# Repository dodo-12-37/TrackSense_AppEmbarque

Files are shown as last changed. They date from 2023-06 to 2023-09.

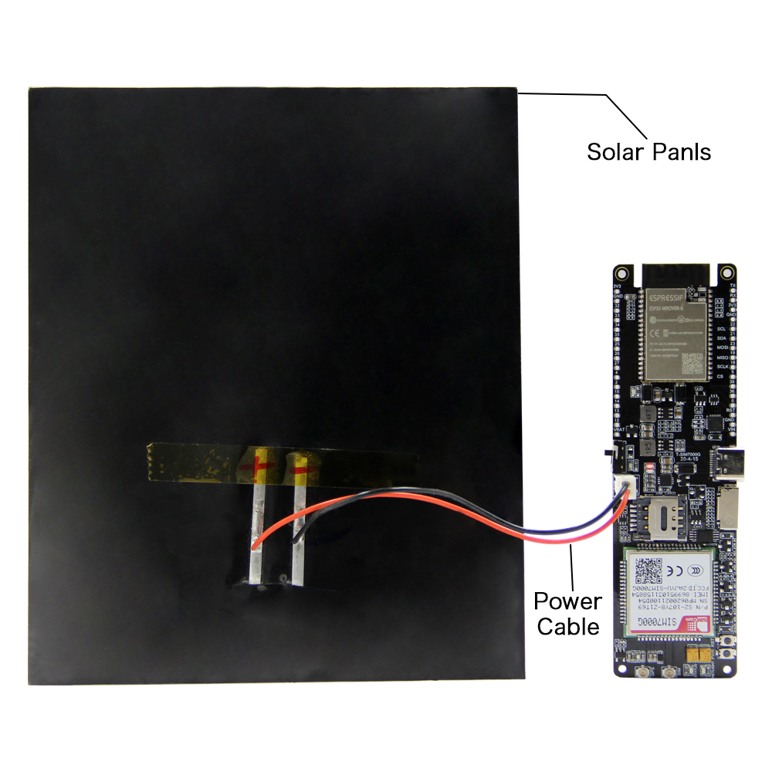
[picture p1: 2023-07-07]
Références Composants/LILYGO T-SIM7000G - ESP32/Installation Panneau Solaire.jpg

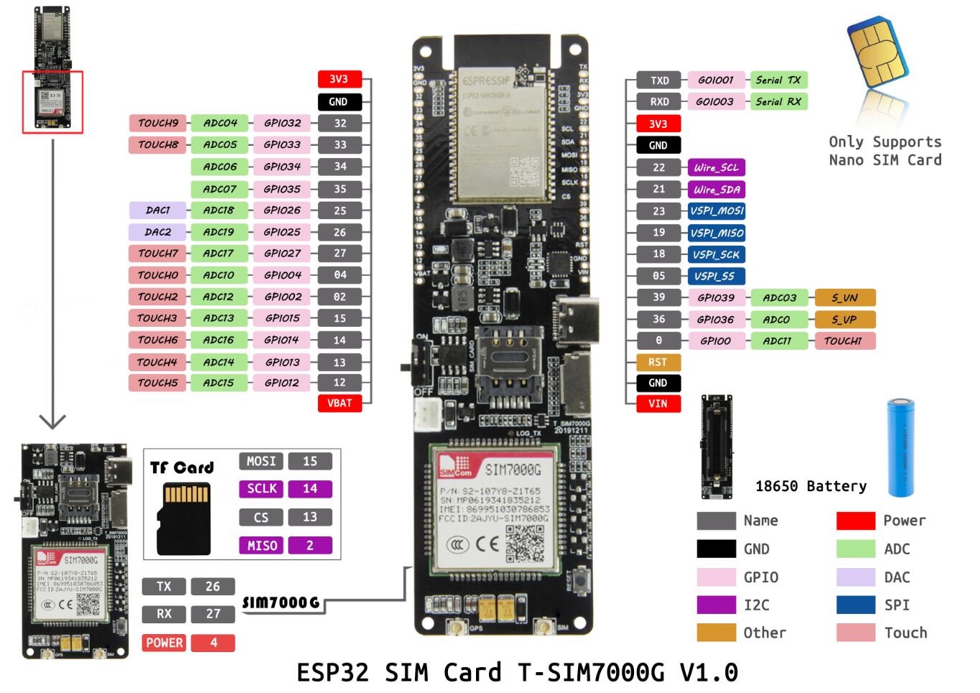
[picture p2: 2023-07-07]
Références Composants/LILYGO T-SIM7000G - ESP32/LILYGO-SIM7000G-ESP32-V1_0_pinout.jpg

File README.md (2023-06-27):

# 420-W57-SF_E23_4394_TrackSense_AppEmbarque
Dépôt de l'Application Embarqué du Projet Synthèse pour le cours de Programmation, bases de données et serveurs – AEC (LEA.D4). 

Nous ferons la création d'un objet connecté nommé le TrackSense. Cette objet sera principalement utilisé sur un vélo ou un piéton.

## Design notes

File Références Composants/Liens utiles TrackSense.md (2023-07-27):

# Liste de liens utiles pour TrackSense

## Pièces achetées
- [TFT Display 1.28 Inch TFT LCD Display Module Round RGB 240*240 GC9A01 Driver 4 Wire SPI Interface 240x240 PCB For Arduino](https://www.aliexpress.com/item/1005004069703494.html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)
  - MEILLEUR LIEN : [**Using GC9A01 Round LCD Modules**](https://dronebotworkshop.com/gc9a01/)
  - [**Library Bodmer/TFT_eSPI**](https://github.com/Bodmer/TFT_eSPI/blob/master/User_Setups/Setup200_GC9A01.h)
  - [Library carlfriess/GC9A01_demo]()
  - [Exemple de code pour l'écran](https://www.makerfabs.com/gc9a01-1.28-inch-round-lcd-module.html)
  - [Adafruit_GC9A01A Library](https://github.com/adafruit/Adafruit_GC9A01A)  
  - [Adafruit GFX Library](https://github.com/adafruit/Adafruit-GFX-Library/blob/master/README.md)
  - [**ESP32 SPI Communication: Set Pins, Multiple SPI Bus Interfaces, and Peripherals (Arduino IDE)**](https://randomnerdtutorials.com/esp32-spi-communication-arduino/)
  - Exemple de code : [Photographic album using ESP32 and GC9A01 round screen](https://giltesa.com/en/2021/01/05/photographic-album-using-esp32-and-gc9a01-round-screen)
  - [Video : GC9A01 Round LCD with ESP32 & Arduino](https://www.youtube.com/watch?v=k2c2zCmC_X0)
  - Très bonne référence complète, mais pas modèle exacte [**Waveshare 1.28inch LCD Module**](https://www.waveshare.com/wiki/1.28inch_LCD_Module)
  - [**Waveshare : 240×240, General 1.28inch Round LCD Display Module, 65K RGB**](https://www.waveshare.com/1.28inch-LCD-Module.htm)
  - [**IPS LCD 1.28″ 240×240 RGB Round Display GC9A01**](https://protosupplies.com/product/ips-lcd-128-round-square-display-gc9a01-copy/)
  - [1.28inch LCD Display Module, IPS Screen, 65K RGB, 240 × 240 Resolution, SPI Interface. ](https://www.waveshare.com/wiki/1.28inch_LCD_Module#Introduction)
  - []()
  - []()
  - []()

- [LILYGO® TTGO T-SIM7000G 4MB / 16MB Module ESP32-WROVER-B Chip SIM Card WiFi Bluetooth 18650 Battery Holder Solar Charge Board](https://www.aliexpress.com/item/1005003094951052.html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)
  - [**Dépot GitHub Officiel LILYGO**](https://github.com/Xinyuan-LilyGO/LilyGO-T-SIM7000G)
  - [T-SIM7000G SIM Development Board ESP32 Wireless Module](https://www.lilygo.cc/products/t-sim7000g?variant=42275516776629)
  - [LILYGO® TTGO Accessories Shield LoRa 868/915 Mhz](https://www.tindie.com/products/lilygo/lilygo-ttgo-accessories-shield-lora-868915-mhz/)
  - [**ACOPTEX Guide to LILYGO T-SIM7000G ESP32 development board- AT communication**](https://acoptex.com/wp/guide-to-lilygo-t-sim7000g-esp32-development-board/)
  - [**LILYGO T-SIM7000G ESP32: Get GPS Data (Latitude, Longitude, Altitude, and more)**](https://randomnerdtutorials.com/lilygo-t-sim7000g-esp32-gps-data/)
  - [**Getting Started with LILYGO T-SIM7000G ESP32 (LTE, GPRS, and GPS)**](https://randomnerdtutorials.com/lilygo-t-sim7000g-esp32-lte-gprs-gps/)
  - [?? GNSS – How to use GNSS feature on Simcom Modules? ??](https://m2msupport.net/m2msupport/gnss-how-to-use-gnss-feature-on-simcom-modules/)
  - []()
  - []()
  - []()
  - [GSM/GPRS/GPS Shield (B), Arduino Shield Based on SIM808 ](https://www.waveshare.com/wiki/GSM/GPRS/GPS_Shield_(B))

- [GY-87 ou HW-290](https://fr.aliexpress.com/item/4000234539826.html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)
  - [Interfacing GY-87 IMU MPU6050 HMC5883L BMP085 Module with Arduino](https://electropeak.com/learn/interfacing-gy-87-10dof-imu-mpu6050-hmc5883l-bmp085-module-with-arduino/)
  - [HMC5883L_Simple Library](https://github.com/sleemanj/HMC5883L_Simple)
  - [GY-87 10DOF MPU6050 HMC5883L BMP180 Sensor Module](https://store.roboticsbd.com/sensors/382-gy-87-10dof-mpu6050-hmc5883l-bmp180-sensor-module-robotics-bangladesh.html)
  - [**Use and Calibrate HMC5883L Digital Compass**](https://www.best-microcontroller-projects.com/hmc5883l.html)
  - []()
  - []()
  - []()

- [MPU-6050]()
  - [**I2C Device Library** The I2C Device Library (i2cdevlib) is a collection of mostly uniform and well-documented classes to provide simple and intuitive interfaces to I2C devices.](https://github.com/jrowberg/i2cdevlib/tree/master/Arduino/MPU6050)
  - [MPU6050 by Electronic Cats - Library for Arduino](https://github.com/ElectronicCats/mpu6050/tree/master)
  - [What is MPU6050?](https://github.com/ElectronicCats/mpu6050/wiki/1.-What-is-MPU6050%3F#features)
  - [VIDEO : ESP32 Web Server with MPU-6050 Accelerometer and Gyroscope (3D object representation)](https://www.youtube.com/watch?v=dXcF-Uqa-gw)
  - []()
  - []()
  - []()

- [Buzzer SFM-27 ou SFM-20B](https://fr.aliexpress.com/item/1005001792688572.html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)
  - [Images dimension buzzer](https://fr.aliexpress.com/item/1005005426676025.html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,scm-url:1007.40050.281175.0,pvid:f82a8dd0-6433-49ed-a130-f7840a425f60,tpp_buckets:668%232846%238107%231934&pdp_npi=3%40dis%21CAD%210.58%210.52%21%21%21%21%21%402103250716890035395333740e7c3e%2112000033021292153%21rec%21CA%21)
  - []()
  - []()
  - []()

- [10 Pack TTP223B Digital Touch Capacitive Sensor Switch Module DIY for Arduino Raspberry Pi](https://www.aliexpress.com/item/1005004822891026.html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)
  - [Vidéo du fonctionnement des boutons](https://www.youtube.com/watch?v=V6ORKSxHLN0)
  - [Tutorial for TTP223 Touch Sensor Module ( Capacitive)](https://www.instructables.com/Tutorial-for-TTP223-Touch-Sensor-Module-Capacitive/)
  - Exemple avec capteur différent : [How to use a TTP223 based touch switch](https://diyusthad.com/2019/06/how-to-use-ttp223-based-touch-switch.html)
  - []()
  - []()
  - [CapacitiveSensor Library : CapacitiveSensor lets you create sensors that can detect touch or proximity.](https://github.com/PaulStoffregen/CapacitiveSensor)
  - [Capacitive Sensing Library](https://playground.arduino.cc/Main/CapacitiveSensor/)
  - [Vidéo explication : Capacitive Sensing Library](https://www.youtube.com/watch?v=jhtY_Hn5jBM)
  - []()
  - []()

- [Connecteur female headers PCB, long, 2.54mm, 11/12mm, 2mm, 3mm, 4mm, 6mm, 8mm, 10mm, 15mm, 20/40 broches](https://fr.aliexpress.com/item/1005003961219838.html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,scm-url:1007.40050.281175.0,pvid:3dd93779-9ecc-4d7b-9a69-51549ba19462,tpp_buckets:668%232846%238116%232002&pdp_npi=3%40dis%21CAD%211.65%211.65%21%21%21%21%21%402101ec1f16884816869006605eff6d%2112000027575194850%21rec%21CA%21)
  - [Dessin connecteurs female headers](https://fr.aliexpress.com/item/4000979967513.html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,scm-url:1007.40050.281175.0,pvid:e7105b2a-5874-40fd-b602-fba5c134012f,tpp_buckets:668%232846%238116%232002&pdp_npi=3%40dis%21CAD%211.0%210.95%21%21%21%21%21%402101ead816884800553916301ef787%2110000013144422244%21rec%21CA%21)
  - []()
  - []()
  - []()
  - []()
  - []()

## Tilt Compass
### Exemple avec bon capteurs (GY-87, MPU-6050, QMC5883L)
- [3 Axis Magnetometer Tilt Compensation](https://www.best-microcontroller-projects.com/magnetometer-tilt-compensation.html)
- [Vidéo Tilt Compensated Digital Compass based on AVR](https://www.youtube.com/watch?v=spmMMIMboPY)
- [Exemple GitHub visakhanc/eCompass](https://github.com/visakhanc/eCompass/blob/master/README.md)
- [Tutorial: How to use the GY-521 module (MPU-6050 breakout board) with the Arduino Uno](https://mschoeffler.com/2017/10/05/tutorial-how-to-use-the-gy-521-module-mpu-6050-breakout-board-with-the-arduino-uno/)
- []()
- []()
- []()
- []()
- []()

### Exemple avec mauvais capteurs
- [How to Use GY511 Module With Arduino [Make a Digital Compass]](https://www.instructables.com/How-to-Use-GY511-Module-With-Arduino-Make-a-Digita/)
- [Tilt Compensated Compass IvenSense MPU-9250 & MPU-6050 accelerometer / gyro & an AK8963 magnetometer](https://www.instructables.com/Tilt-Compensated-Compass/)
- []()
- []()
- []()
- []()
- []()
- []()
- []()
- []()

## Create PCB with EasyEDA Designer
- [Document Tutorial](https://docs.easyeda.com/en/Introduction/Schematic-Capture/index.html)
- [How to Make Custom ESP32 Board in 3 Hours | Full Tutorial](https://www.youtube.com/watch?app=desktop&v=S_p0YV-JlfU&feature=youtu.be)
- [Get quote for PCB - JLCPCB](https://cart.jlcpcb.com/quote)
- [Explication des connecteurs JST](https://www.mattmillman.com/info/crimpconnectors/common-jst-connector-types/#shsr)
- [Autre explication des connecteurs JST](https://www.ourpcb.com/jst-connector-types.html)
- []()
- []()
- []()
- []()
- []()
- []()

# Résumé 04 juillet

- [x] Ajouter 2ème rangée de pins pour connecter les CHEVELUS. 
- [x] Mesuré le speaker piézo et y trouver une place.
- [x] Ajouter un connecteur pour le speaker piézo.
- [x] Deux connectiques pour l'écran TFT. Un sur la TFCard et un sur le VSPI.
- [x] Ajouter deux connecteurs pour les boutons. (Vérifier pour une résistance???)
- [x] Ajouter des résistances pour les connecteurs I2C.
- [x] Enlever les connecteurs I2C en surplus.
- [x] Mettre le GY-87 directement sur le PCB.
- [x] Mettre des pins VCC et GND pour les boutons. (Et pins infos aussi ???)
- [ ] 

Fusion 360 fabriquer boitier

cd "C:\Program Files\Oracle\VirtualBox\"
VBoxManage.exe modifyvm "VM_MacOS_AppMobile_2" --cpuidset 00000001 000106e5 00100800 0098e3fd bfebfbff
VBoxManage setextradata "VM_MacOS_AppMobile_2" "VBoxInternal/Devices/efi/0/Config/DmiSystemProduct" "iMac19,3"
VBoxManage setextradata "VM_MacOS_AppMobile_2" "VBoxInternal/Devices/efi/0/Config/DmiSystemVersion" "1.0"
VBoxManage setextradata "VM_MacOS_AppMobile_2" "VBoxInternal/Devices/efi/0/Config/DmiBoardProduct" "Iloveapple"
VBoxManage setextradata "VM_MacOS_AppMobile_2" "VBoxInternal/Devices/smc/0/Config/DeviceKey" "ourhardworkbythesewordsguardedpleasedontsteal(c)AppleComputerInc"
VBoxManage setextradata "VM_MacOS_AppMobile_2" "VBoxInternal/Devices/smc/0/Config/GetKeyFromRealSMC" 0
VBoxManage setextradata "VM_MacOS_AppMobile_2" "VBoxInternal/TM/TSCMode" "RealTSCOffset"

Gravité	Code	Description	Projet	Fichier	Ligne	État de la suppression
Erreur	APT2098	xml_microsoft_maui_essentials_fileprovider_file_paths.xml.flat: error: failed to open file. "xml_microsoft_maui_essentials_fileprovider_file_paths.xml.flat: error: failed to open file.".	BluetoothLEConnection	C:\Program Files\dotnet\packs\Microsoft.Android.Sdk.Windows\32.0.485\tools\Xamarin.Android.Aapt2.targets	123

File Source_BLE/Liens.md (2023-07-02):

# Liens diverses

- [Architecture Bluetooth de l'ESP (en)](file:///D:/T%C3%A9l%C3%A9chargements/esp32_bluetooth_architecture_en-1.pdf)
- [Exemple de Mise en oeuvre du Bluetooth BLE sur ESP32 (fr)](http://tvaira.free.fr/bts-sn/activites/activite-ble/activite-ble-esp32.html)
- [Exemple ESP32 BLE Server and Client (en)](https://randomnerdtutorials.com/esp32-ble-server-client/)
- [Exemple ESP32 BLE Server and Client (en)](https://randomnerdtutorials.com/esp32-bluetooth-low-energy-ble-arduino-ide/)
- [Exemple ESP32 BLE Server and Client (en)](https://randomnerdtutorials.com/esp32-ble-server-client/#ESP32-BLE-Server)
- [Référence GitHub](https://github.com/nkolban/ESP32_BLE_Arduino)
- [Référence GitHub](https://github.com/nkolban/esp32-snippets)
- [Liste des UUID normés](https://www.bluetooth.com/specifications/assigned-numbers/)

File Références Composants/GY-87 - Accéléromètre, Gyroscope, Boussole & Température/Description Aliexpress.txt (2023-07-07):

 Description

10DOF modules (three-axis gyroscope + triaxial accelerometer + three-axis magnetic field + Pressure)

Immersion Gold PCB process

Using the chip: MPU6050 + HMC5883L + BMP180

Power supply :3-5v

Means of communication: IIC communication protocol (fully compatible with 3-5v system containing LLC circuit)

Size: 2.2cm * 1.7cm

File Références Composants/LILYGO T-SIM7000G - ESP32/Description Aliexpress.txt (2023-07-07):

Description :

Hardware Specifications

Main chip

ESP32-WROVER-B,SIM7000G

Flash Memory

4M Flash / 8M PSRAM

Interface

USB,SD Card,Solar Input interface

Car Clock

40MHz

Button

Reset,Power switch

SIM Card Size

Nano SIM Card

Antenna

SIM Antenna，GPS Antenna

Operating Temperature Range

-40-85 degrees

Power Specifications

Working Voltage

5v input

Charging Current

780mA

Working Curent

About 200mA

Solar input voltage range

4.4-6v

USB

TYPE-C 3.0

JST connector

2pin 2.0MM

Battery holder

18650 battery holder

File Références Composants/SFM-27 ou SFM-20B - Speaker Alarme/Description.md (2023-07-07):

**Description:**  
[Lien info (pas celui acheter...)](https://www.aliexpress.com/item/1005005560547607.html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)

- Color: Black
- Alarm Diameter: 22mm/0.86"
- Alarm Height: 10mm/0.39”
- 2 Mounting Holes distance: 30mm/1.18"
- 2 Wires length: 90mm/3.54"
- Buzzer Type: Piezoelectric
- Sound Pressure Level: 95 dB
- Rate Voltage: 12V DC
- Operating Voltage: 3 - 24V
- Max Current Rating: 10mA
- Frequency: 3900±500Hz
- Drive Method: Drive Circuit Built in Mounting Holes
- Sound: "Di" Continuous

**Package includes:**
1 x 95DB Piezoelectric Buzzer Alarm

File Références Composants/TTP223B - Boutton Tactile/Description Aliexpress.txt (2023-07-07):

Description
Report Item

The Digital Sensor TTP223B Module Capacitive Touch Switch is based on a touch-sensing IC (TTP223B) capacitive touch switch module. Allows you to remove the worry of conventional push-type keys.

Digital Capacitive Touch Switch Module is based on TTP223B. Normally, it outputs low and keeps at low power state. When a touch is sensed on the circular marked region, it outputs high and switches to the quick response state. When not being touched for 12 seconds, it switches to low power state again.

If the module is mounted in the surfaces of non-metallic materials such as plastic, glass, acrylic, you can make the keys hidden in the walls and desks.

In addition to the thin paper ( non-metallic ) covering the surface of the module, as long as the correct location of the touch, you can make hidden in the walls, desktops and other parts of buttons.

Touch Sensor Interface:
Control Interface: A total of three pins (GND, VCC, SIG), GND to the ground, VCC is the power supply, SIG digital signal output pin
Power Indicator: Green LED, power on the right that is shiny
Touch area: Similar to a fingerprint icon inside the area, you can touch the trigger finger.
Positioning holes: 4 M2 screws positioning hole diameter is 2.2mm, the positioning of the module is easy to install, to achieve inter-module combination.

Features :
Low power consumption
Power supply for 2 ~ 5.5V DC
Can replace the traditional touch of a button
Four M2 screws positioning holes for easy installation
Output Pin Sink Current (@ VCC = 3V, VOL = 0.6V) : 8 mA
Output pin pull-up current (@ VCC = 3V, VOH = 2.4V) : 4 mA

Package Includes :
10 x Digital Sensor TTP223B Module Capacitive Touch Switch

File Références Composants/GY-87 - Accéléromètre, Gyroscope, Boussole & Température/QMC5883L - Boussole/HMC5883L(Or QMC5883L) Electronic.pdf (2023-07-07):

# HMC5883L(Or QMC5883L) Electronic Compass

In ourProfessional Kit, there exist two kinds of Compass module. One kind uses HMC5883L module, the other uses QMC5883L module. You will get one of them when you get the Professional Kit. They don't have too much difference. HMC5883Lis made by Honeywell. but because the production is about to be stopped, so we use a similar compass module-QMC5883Linstead. QMC5883Lis made by a Chinese company, they get the production authorization of HMC5883L from Honeywell, and rename it QMC5883L. So QMC5883Land HMC5883Lbasically are the same, they shares the same hardware design. Just their register is a bit different. We only need to change the software a bit.

When you got the Professional Kit, please check which compass module you get based on the following picture. The HMC5883Lhas a label "L883"on it, while QMC5883Lcomes with "5883"

HMC5883LElectronic Compass | QMC5883LElectronic Compass
HMC5883LElectronic Compass | QMC5883LElectronic Compass

# HMC5883L Electronic Compass

## Introduction

3-Axis Compass module, I2C based Honeywell HMC5883 digital compass. This ASIC is equipped with high resolution HMC118X magneto-resistive sensors and a 12-bitADC. It provides compass heading accuracy up to 1° to 2°. Signal conditioning like amplification, automatic degaussing strap drivers and offset cancellation are inbuilt. This module also includes a MIC5205-2.5 voltage regulator for power supply requirement. Hence user can connect any 3.3V to 6V DC power supply.

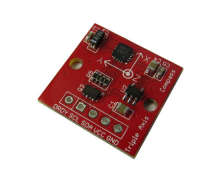
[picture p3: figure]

## Features

- I2C interface
- Compatible with 3.3V-5.0V voltage level
- Max 116Hz output rate
- High heading accuracy

## Usage

Below is a registermap that might help you understand what you can get from this module. There are totally 13 registers provided by HMC5883L. Out of three registers - Configuration registerA, Configuration RegisterB and Mode Register decide the working mode of the device. The remaining registers are read only data output registers, status register and identification registers.

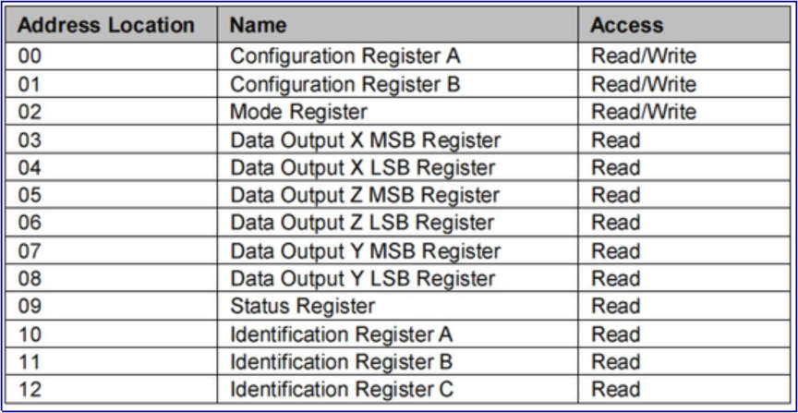
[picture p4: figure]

This demo is going to show you how to read raw data, how to calibrate the data with your local magnetic declination angle and how to get heading angle.
First off, before any action you are going to take, you need to prepare a parameter you are going to use in your demo. That's your local magnetic declination.
You can find it out in degree via the magnetic declination webpage. For example, mine is -2°37’, which is -2.617 degree.
Then transfer it from degree to radians, and there you get the "declinationAngle". For example, in my case, declinationAngle = -2.617 / （2*π）= -0.0456752665 rad. Three significant figures are enough. So I would shorten it into -0.0456 rad. And this is the parameter you are going to replace the value of "declinationAngle"in the domo code with.
Now let's start to run your compass.
1. Connect the HMC5883LElectronic Compass to Arduino via the I2C port.
2. Download the library file: HMC5883L Compass library. Unzip it into the libraries file of Arduino IDE by the path: ..\arduino-1.0.1\libraries.
3. Open the demo by the path:File -> Example ->Digital Compass ->HMC5883L_Example.
4. Replace the value of variable "declinitionAngle"with the one you've figured out already.
5. Upload the Code.
6. Check the output result by opening the serial monitor.

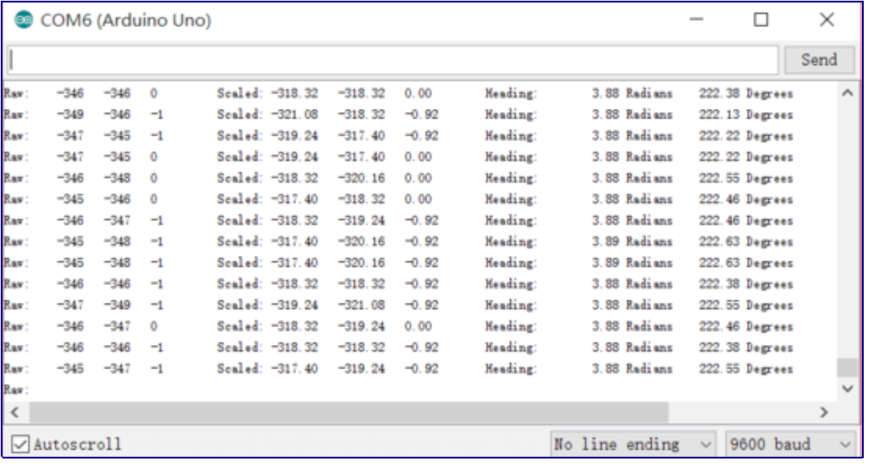
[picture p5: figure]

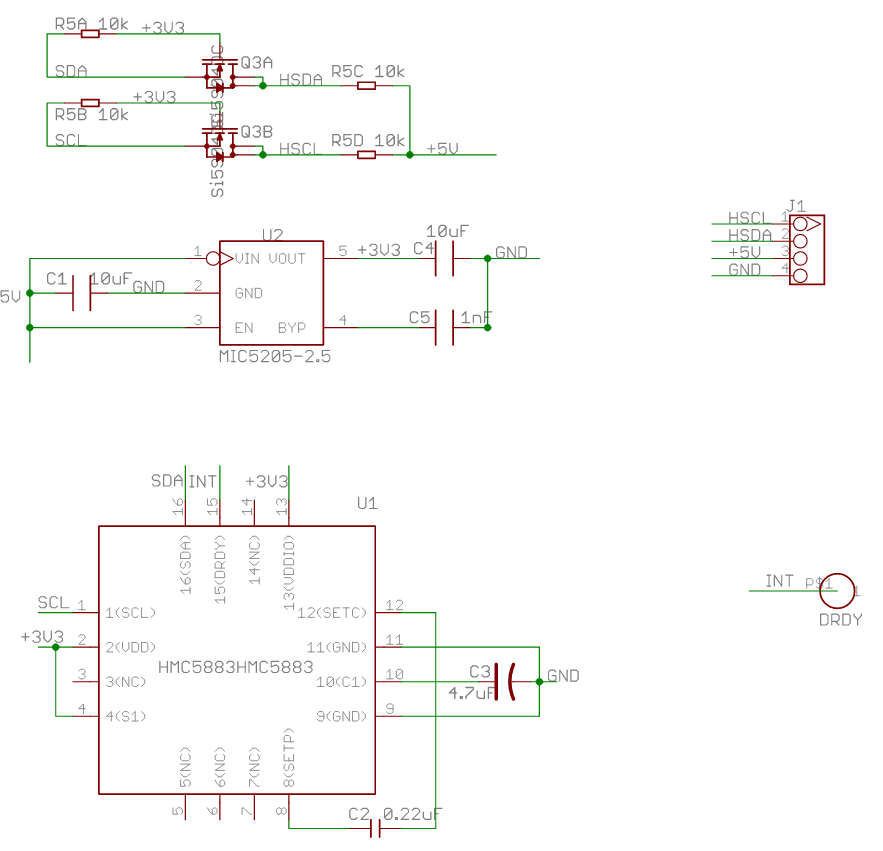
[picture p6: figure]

# QMC5883L Electronic Compass

## Introduction

3-Axis Compass module, I2C based QMC5883 digital compass. This ASIC is equipped with high resolution magneto-resistive sensors and a 16-bit ADC. It provides compass heading accuracy up to 1° to 2°. Signal conditioning like amplification, automatic degaussing strap drivers and offset cancellation are inbuilt. This module also includes a MIC5205-2.5 voltage regulator forpower supply requirement. Hence user can connect any 3.3V to 6V DC power supply.

Features

- I2C interface
- Compatible with 3.3V-5.0V voltage level
- Max 200Hz output rate
- High heading accuracy

## Usage

Below is a registermap that might help you understand what you can get from this module. There are totally 14 registers provided by QMC5883L. Two Control Registers decide the working mode of the device, they come with address "09H"and "0AH". Most of the remaining registers are read only data output registers, status register and identification registers.

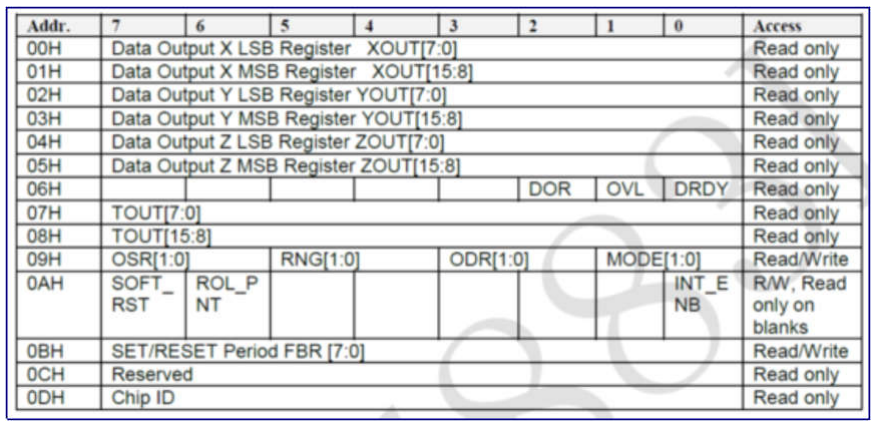
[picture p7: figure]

In this example we will make the module output the heading angle between South and this module.

### 1. Connect the QMC5883LElectronic Compass to Arduino via the I2C port. Make sure the

QMC5883L module is horizontal。
2. Download the library file: QMC5883L Compass library. Unzip it into the libraries file of Arduino IDE by the path: ..\arduino-1.0.1\libraries.
3. Open the demo by the path:File -> Example ->Digital Compass ->QMC5883L_Example.
4. Upload the Code.
5. Check the output result by opening the serial monitor.

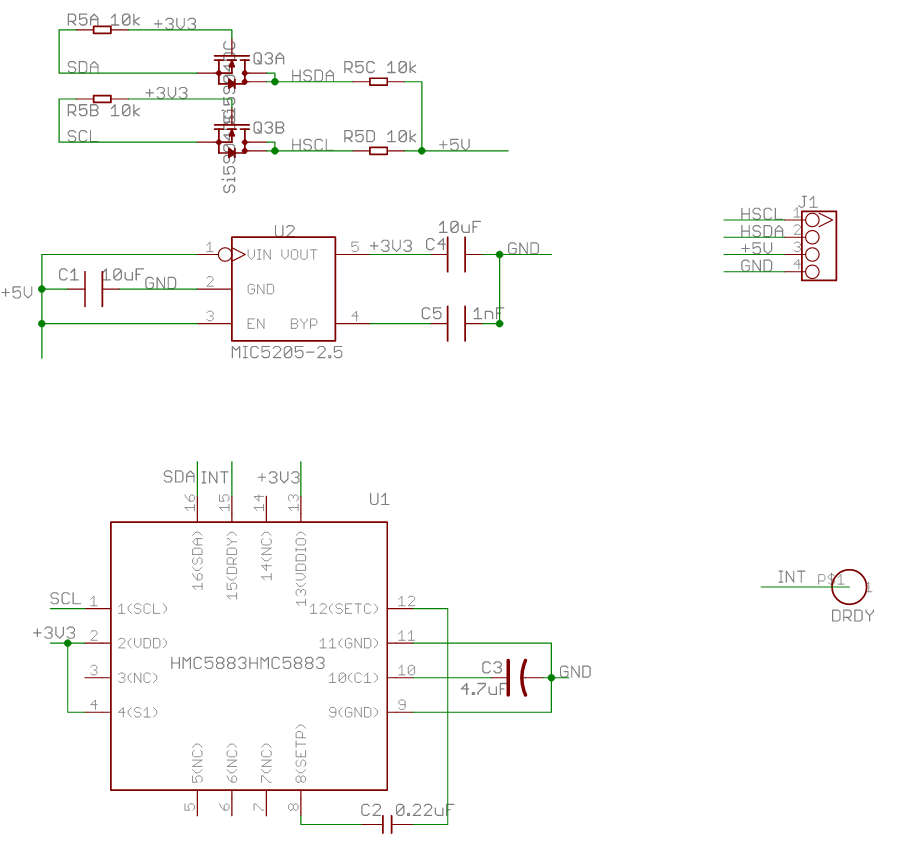
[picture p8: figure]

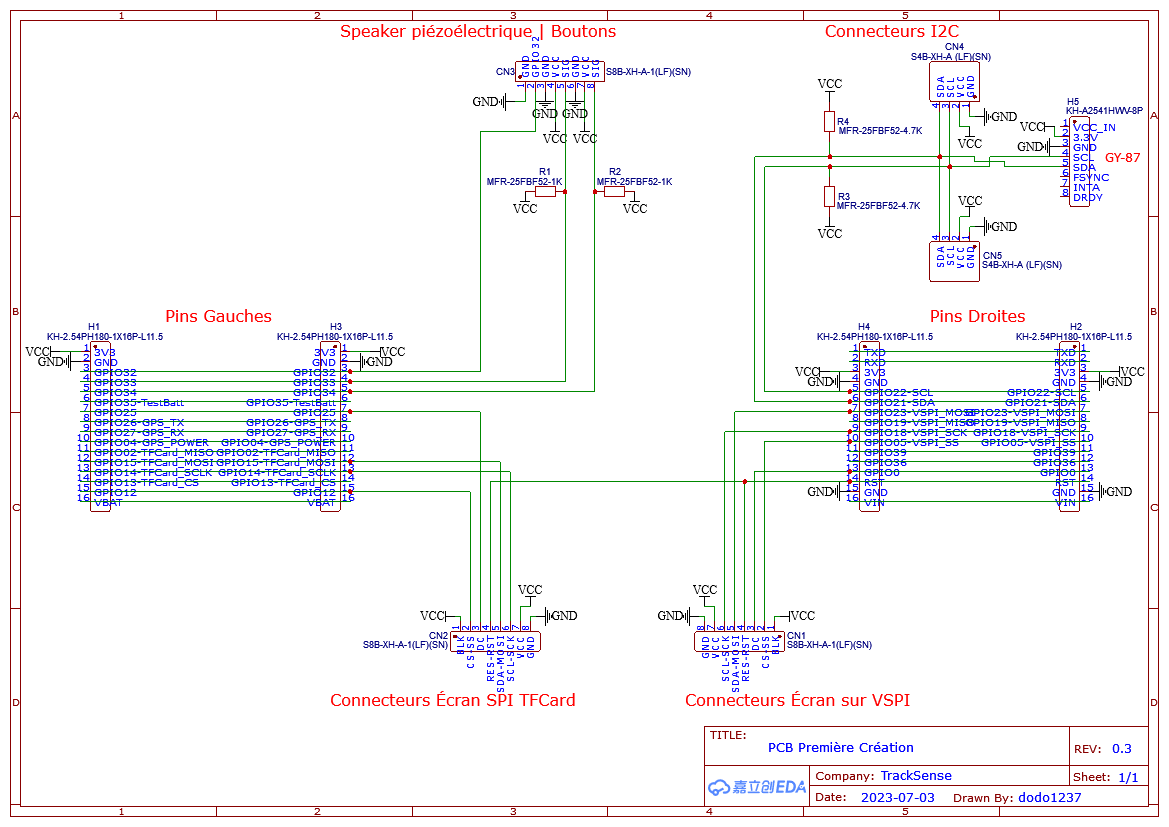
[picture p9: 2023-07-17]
Références Composants/PCB TrackSense/V1.0/Schematic_TrackSense_2023-07-17.png

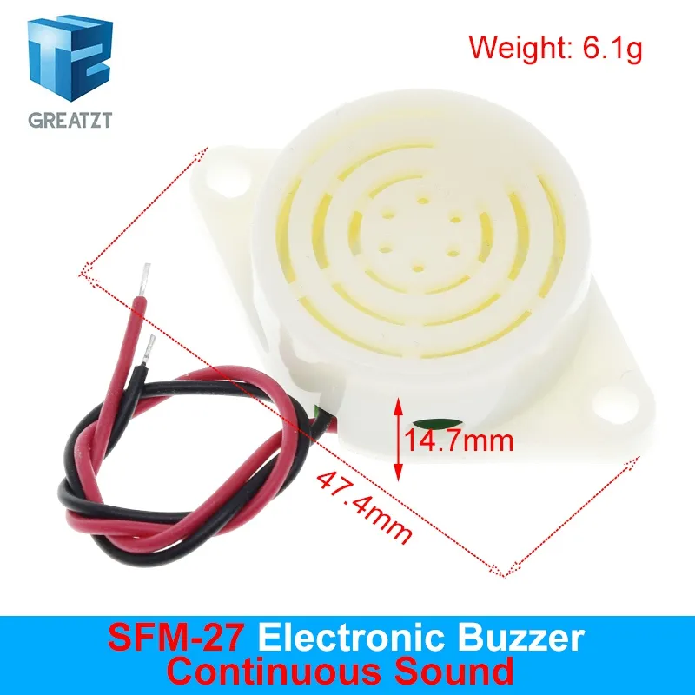
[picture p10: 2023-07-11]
Références Composants/SFM-27 ou SFM-20B - Speaker Alarme/SFM-27/Dimensions_SFM-27_ContinuousSound.jpg

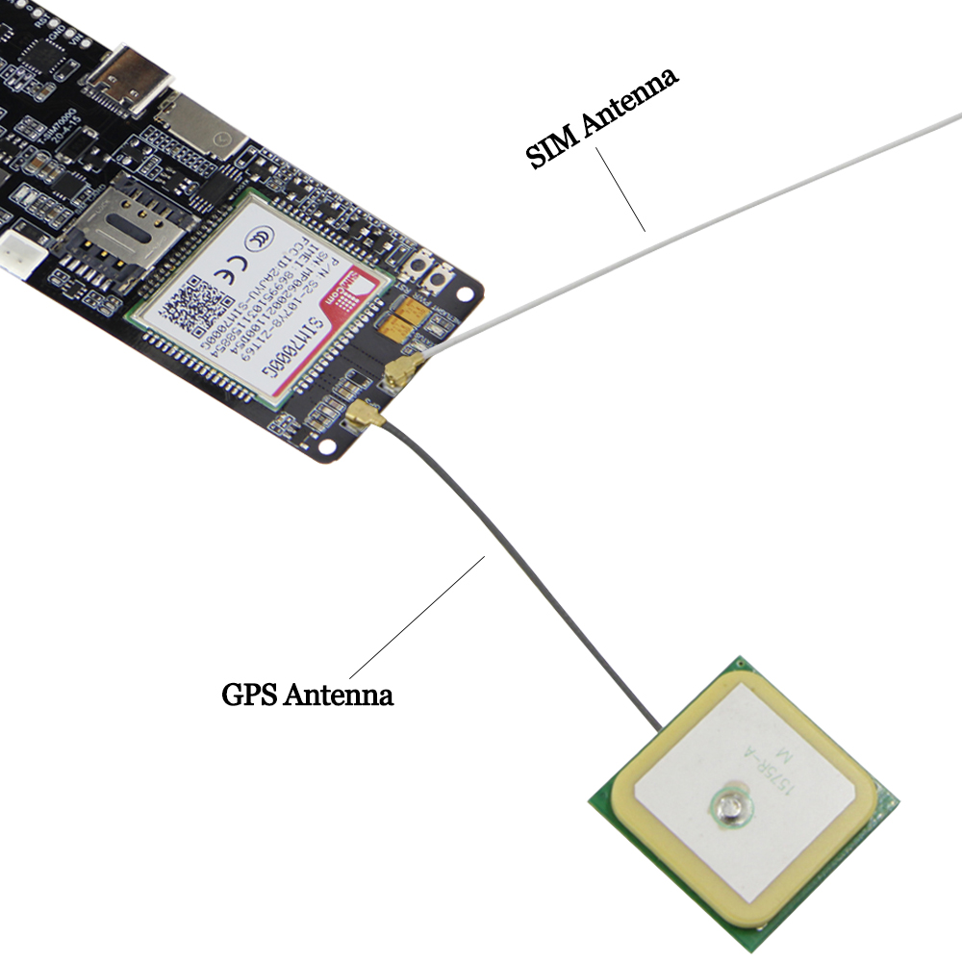
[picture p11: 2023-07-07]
Références Composants/LILYGO T-SIM7000G - ESP32/Emplacement des Antennes.jpg

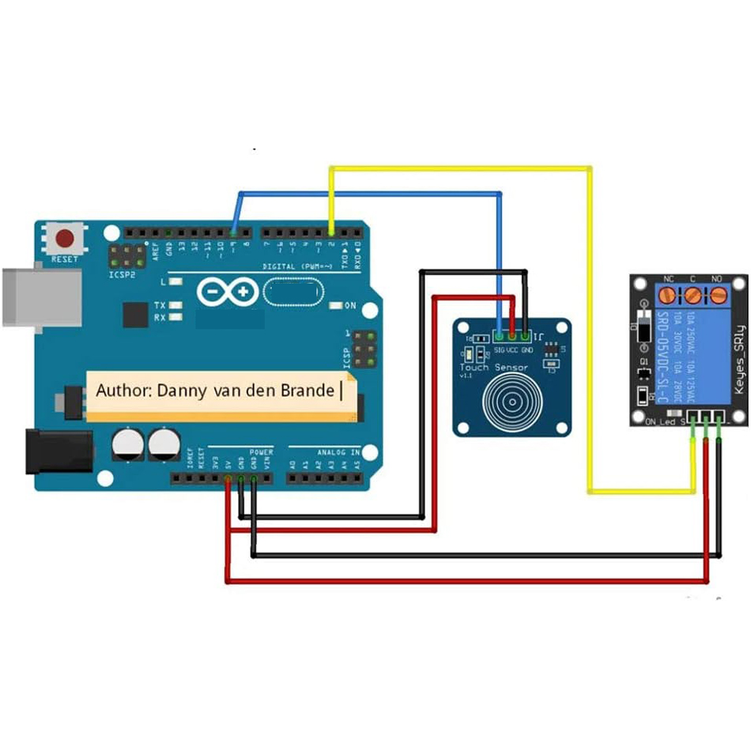
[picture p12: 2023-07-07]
Références Composants/TTP223B - Boutton Tactile/Exemple Connexion Arduino.jpg

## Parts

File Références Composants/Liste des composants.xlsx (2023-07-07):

 |  |  |  |  |  | 240.62 $
Composants | Fonctions | Type Connexion | Prix Unitaire | Nb / Lot | Nb Commandé | Prix Total | Nom Aliexpress | Item Commandé
LILYGO T-SIM7000G ESP32 16MB V1.1 | Microcontrôleur, LTE, GPS, MicroSD, Batterie, USB | - | 49.28 $ | 1 | 4 | 197.12 $ | LILYGO® TTGO T-SIM7000G 4MB / 16MB Module ESP32-WROVER-B Chip SIM Card WiFi Bluetooth 18650 Battery Holder Solar Charge Board | https://www.aliexpress.com/item/1005003094951052.html?curPageLogUid=yhWCcz28lw2N
GC9A01 | Affichage | SPI | 4.01 $ | 1 | 4 | 16.04 $ | TFT Display 1.28 Inch TFT LCD Display Module Round RGB 240*240 GC9A01 Driver 4 Wire SPI Interface 240x240 PCB For Arduino | https://www.aliexpress.com/item/1005004069703494.html?srcSns=sns_Copy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
GY-87 | Boussole, Accéléromètre & Gyroscope, Température | I2C | 3.74 $ | 1 | 4 | 14.96 $ | TZT GY-87 10DOF Module MPU6050 HMC5883L BMP180 GY87 Sensor Module GY87 For Arduino | https://www.aliexpress.com/item/4000234539826.html?curPageLogUid=aoOXPM3ZuVVH
Carte SIM Hologram | Carte SIM pour LTE | - | 5.00 $ | 1 | 1 | 5.00 $ | - | https://www.hologram.io/pricing/
SFM-27 ou SFM-20B | Alarme Antivol - Buzzer Piézoélectrique | PIN | 0.75 $ | 1 | 4 | 3.00 $ | 95DB Alarm High-decibel DC 3-24V 12V Electronic Buzzer Beep Alarm Intermittent Continuous Beep for Arduino Car Van SFM-27 | https://www.aliexpress.com/item/1005001792688572.html
TTP223B | Boutons Tactile | PIN | 2.26 $ | 10 | 1 | 2.26 $ | 10 Pack TTP223B Digital Touch Capacitive Sensor Switch Module DIY for Arduino Raspberry Pi | https://www.aliexpress.us/item/1005004822891026.html
Female Headers 1x8p, Pattes 11mm, 2.54mm | Connecteurs Shield Hermaphrodite pour PCB | - | 1.12 $ | 10 | 2 | 2.24 $ | Embase femelle à longues jambes empilables pour Ardu37Shield Stlxy, 10/15mm, 1x2, 3, 4, 6, 8, 2.54 broches, 10 pièces | https://fr.aliexpress.com/item/4000979967513.html?scm_id=1007.40050.281175.0&scm-url=1007.40050.281175.0
Composants Parent | Sous-Composants | Fonctions | Type Connexion
LILYGO T-SIM7000G ESP32 16MB V1.1 |  | LTE | -
LILYGO T-SIM7000G ESP32 16MB V1.1 |  | GPS | Serial TX-RX
LILYGO T-SIM7000G ESP32 16MB V1.1 |  | MicroSD | SPI
LILYGO T-SIM7000G ESP32 16MB V1.1 | v4.2BR/EDR and BLE standard | Bluetooth | -
LILYGO T-SIM7000G ESP32 16MB V1.1 | 18650 battery holder | Batterie | -
LILYGO T-SIM7000G ESP32 16MB V1.1 | CP2104 | USB | Serial TX-RX
GY-87 | MPU6050 | Accéléromètre & Gyroscope | I2C
GY-87 | QMC5883L (HMC5883L ?) | Boussole | I2C
GY-87 | BMP180 | Température | I2C

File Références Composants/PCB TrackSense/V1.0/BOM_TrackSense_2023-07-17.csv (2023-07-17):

ID | Name | Designator | Footprint | Quantity | Manufacturer Part | Manufacturer | Supplier | Supplier Part | Price | Pins | JLCPCB Part Class | Contributor | Package Display | Resistance | link
1 | S8B-XH-A-1(LF)(SN) | CN1,CN2,CN3 | CONN-TH_S8B-XH-A-1-LF-SN | 3 | S8B-XH-A-1(LF)(SN) | JST Sales America | LCSC | C495697 | 0.212 | 8 | Extended Part | LCSC
2 | S4B-XH-A (LF)(SN) | CN4,CN5 | CONN-TH_S4B-XH-A-LF-SN | 2 | S4B-XH-A(LF)(SN) | JST | LCSC | C157925 | 0.088 | 4 | Extended Part | LCSC
3 | KH-2.54PH180-1X16P-L11.5 | H1,H2,H3,H4 | HDR-TH_16P-P2.54-V-M | 4 | KH-2.54PH180-1X16P-L11.5 | kinghelm(金航标) | LCSC | C2905491 | 0.098 | 16 | Extended Part | LCSC
4 | KH-A2541HWV-8P | H5 | HDR-TH_8P-P2.54-V-F | 1 | KH-A2541HWV-8P | kinghelm(金航标) | LCSC | C2833314 | 0.209 | 8 | Extended Part | LCSC
5 | MFR-25FBF52-1K | R1,R2 | RES-TH_BD2.4-L6.3-P10.30-D0.6 | 2 | MFR-25FBF52-1K | YAGEO(国巨) | LCSC | C1364484 | 0.018 | 2 | Extended Part | lcsc | No | 1kΩ | https://atta.szlcsc.com/upload/public/pdf/source/20210730/C1364484_DDDEEE83E7C000729FE63E4A4E9762A5.pdf
6 | MFR-25FBF52-4.7K | R3,R4 | RES-TH_BD2.4-L6.3-P10.30-D0.6 | 2 | MFR-25FBF52-1K | YAGEO(国巨) | LCSC | C1364484 | 0.018 | 2 | Extended Part | lcsc | No | 1kΩ | https://atta.szlcsc.com/upload/public/pdf/source/20210730/C1364484_DDDEEE83E7C000729FE63E4A4E9762A5.pdf

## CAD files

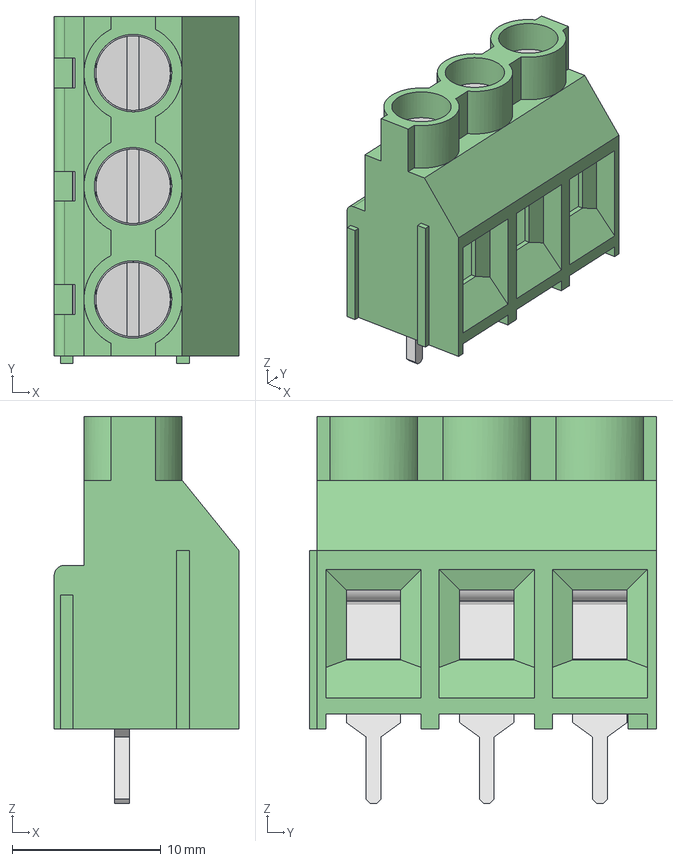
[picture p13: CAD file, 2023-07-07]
Références Composants/Boitier TrackSense/Modèles 3D/EXUUNN EX636-7.26 3-Port v3.iges
12.4 x 23.3 x 26.0 mm

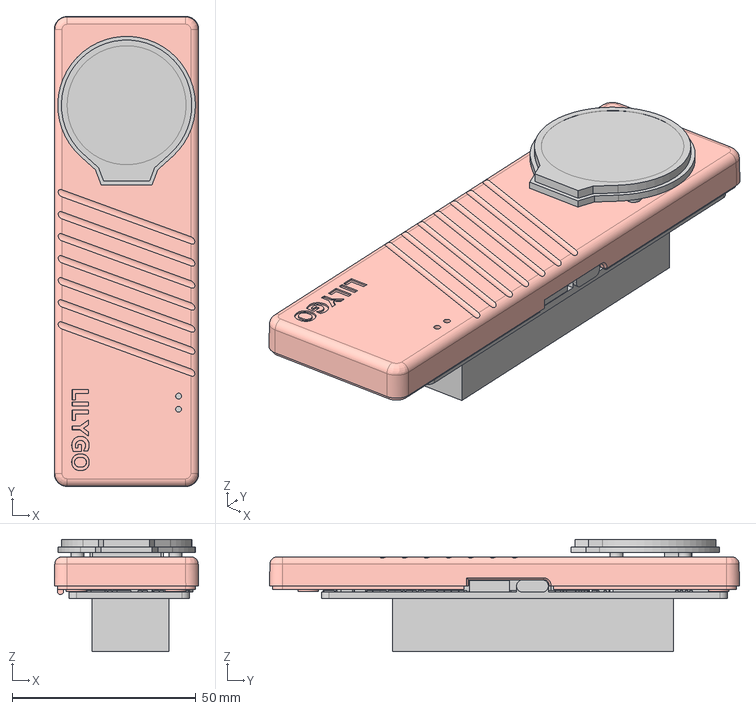
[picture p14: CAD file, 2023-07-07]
Références Composants/Boitier TrackSense/t-sim7000g-shell + GC9A01 TFT LCD Display v1.step
39.3 x 128.0 x 30.6 mm
006_02_T-SIM7000G-A-COVER
T-SIM7000G_6_08_

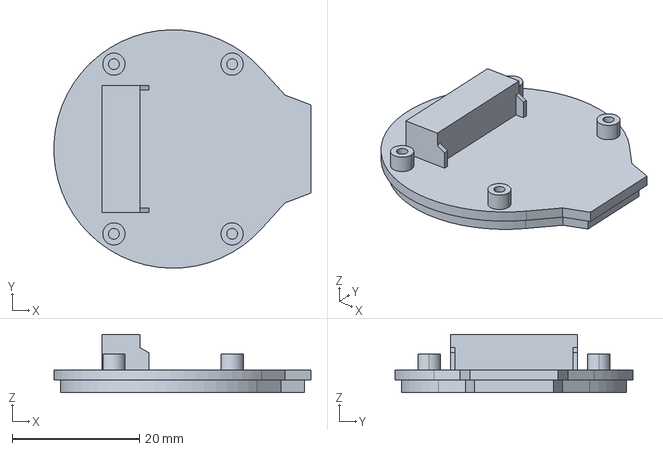
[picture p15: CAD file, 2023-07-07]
Références Composants/GC9A01 - TFT LCD Display Module/Modèles 3D/1.28inch_LCD_Module_3D_Drawing/1.28inch LCD Module 3D Drawing/0508.stp
40.4 x 37.5 x 9.20 mm

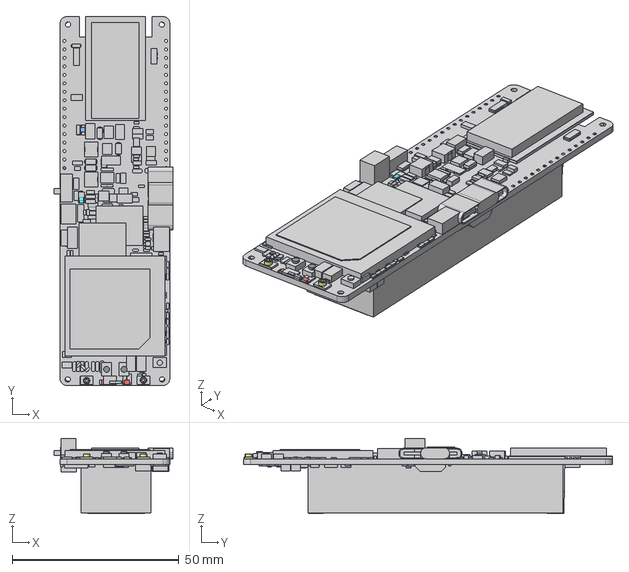
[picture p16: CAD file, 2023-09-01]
Références Composants/LILYGO T-SIM7000G - ESP32/Lilygo GitHub - Modèle 3D/Comparaison t-sim7000G & t-sim7600g-h.step
35.7 x 110.6 x 22.6 mm

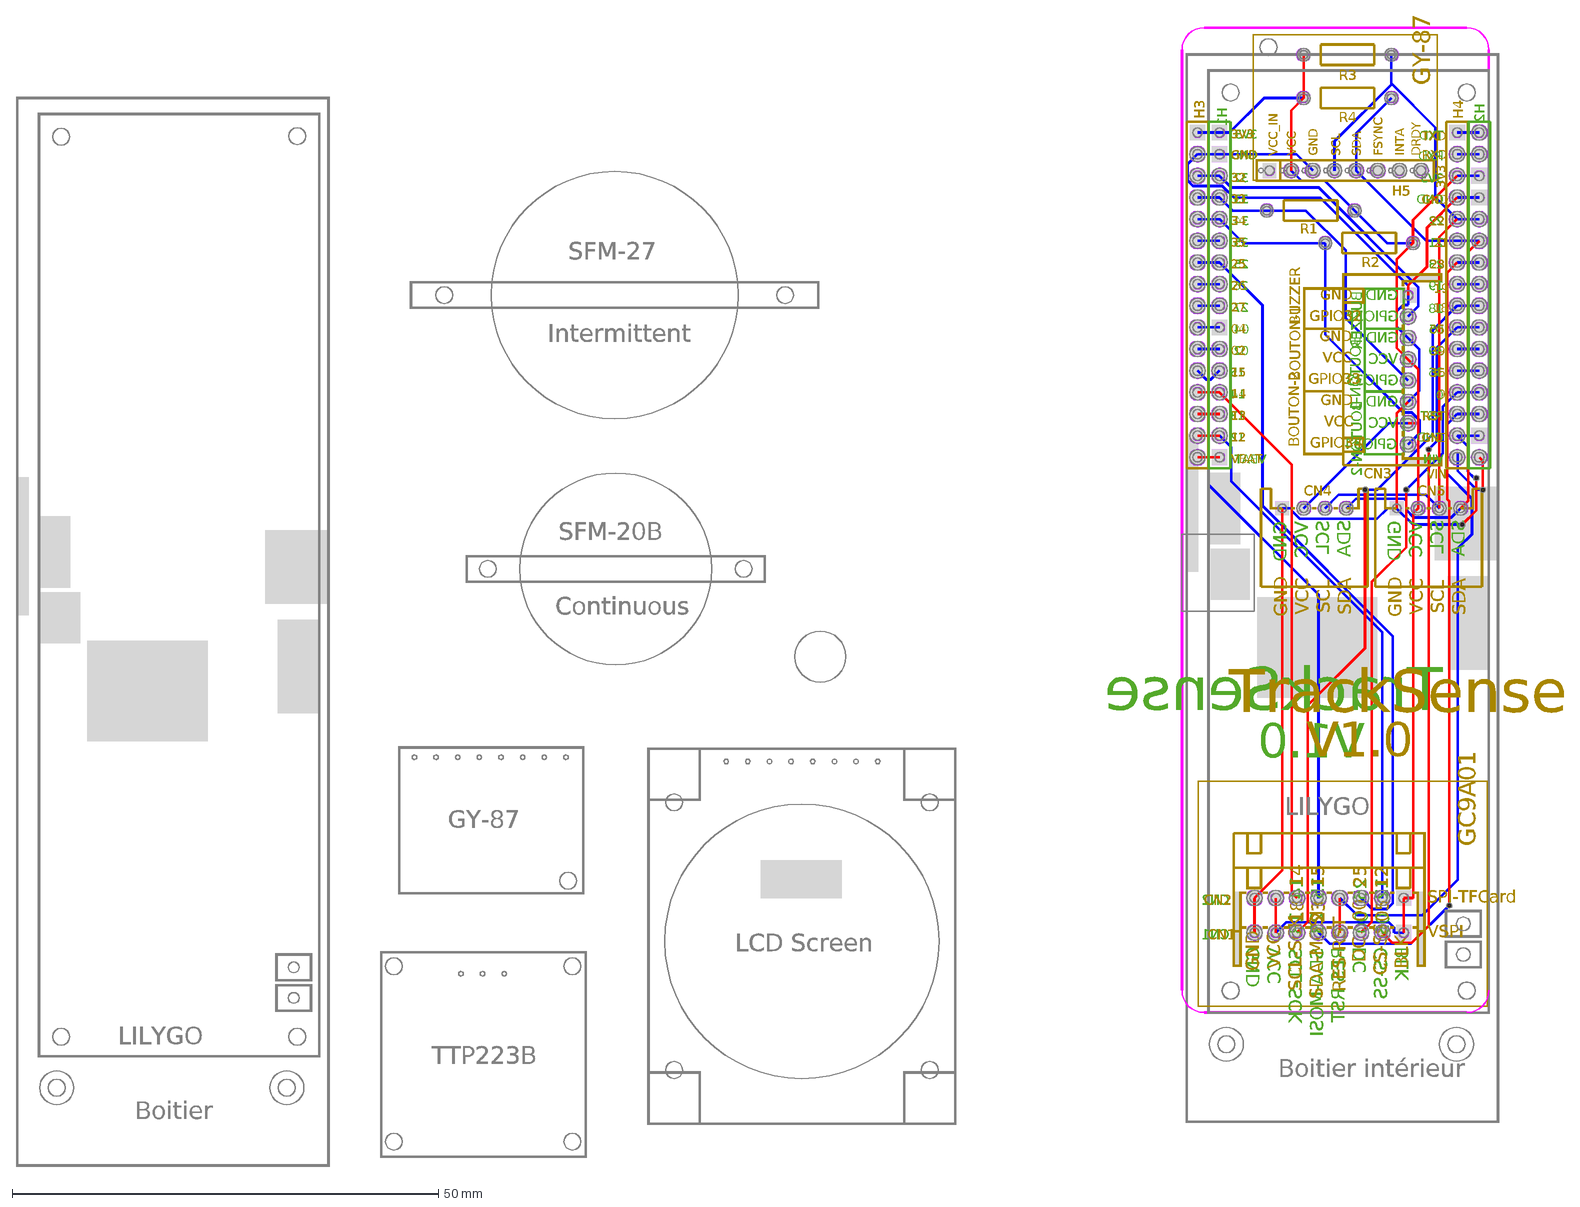
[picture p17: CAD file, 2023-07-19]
Références Composants/PCB TrackSense/V1.0/PCB_TrackSense_Big_115.54X36mm_V1.0_2023-07-17.dxf
TrackSense
V1.0
3V3
GND
32
33
34
35
25
26
27
04
02
15
14
13
12
VBAT
VIN
RST
0
36
39
05
18
19
23
21
22
RXD
TXD
SDA
SCL
VCC
GPIO34
GPIO33
GPIO32
BUZZER
BOUTON-1
BOUTON-2
BLK
CS-SS
DC
RES-RST
SDA-MOSI
SCL-SCK
CN1
CN2
00
LILYGO
Boitier intérieur
TTP223B
GY-87
LCD Screen
Continuous
SFM-20B
Intermittent
SFM-27
Boitier
VCC_IN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

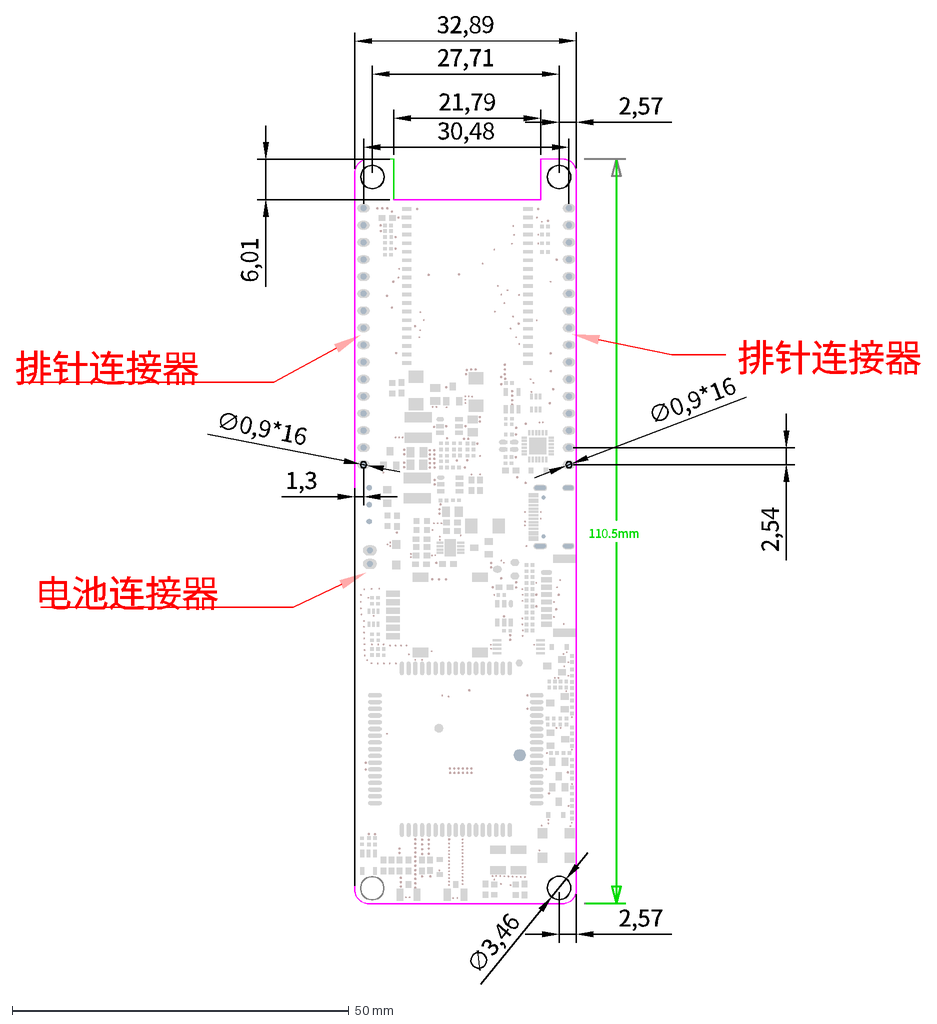
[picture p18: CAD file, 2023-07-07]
Références Composants/LILYGO T-SIM7000G - ESP32/Lilygo GitHub - Modèle 3D/T-SIM7000G.dxf
110.5mm
32,89
27,71
2,57
∅3,46
21,79
6,01
电池连接器
排针连接器
∅0,9*16
2,54
30,48
1,3

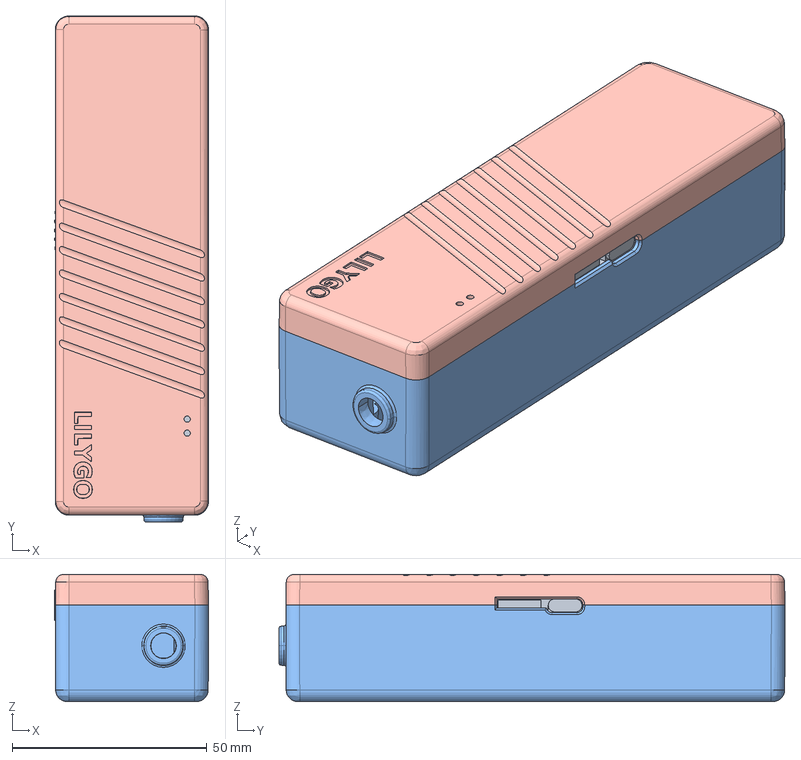
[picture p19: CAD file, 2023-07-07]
Références Composants/LILYGO T-SIM7000G - ESP32/Lilygo GitHub - Modèle 3D/t-sim7000g-shell.stp
39.5 x 129.8 x 32.6 mm
007_02_T-SIM7000G-B-COVER
006_02_T-SIM7000G-A-COVER
003_01_A7672-C-COVER
T-SIM7000G_6_08_

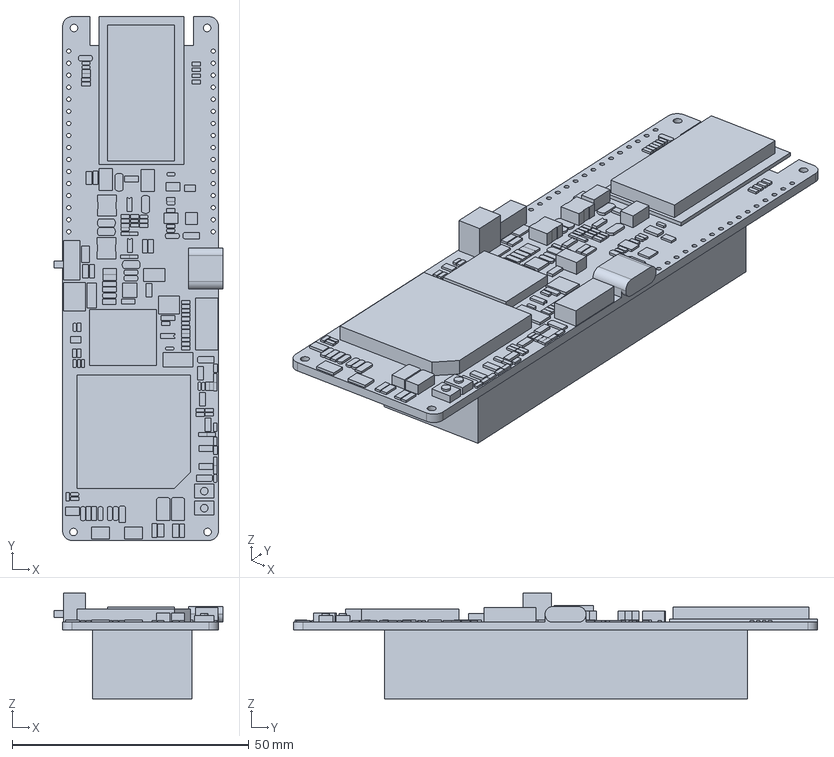
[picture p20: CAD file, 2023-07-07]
Références Composants/LILYGO T-SIM7000G - ESP32/Lilygo GitHub - Modèle 3D/T-SIM7000G(6.08).stp
35.7 x 110.6 x 22.4 mm

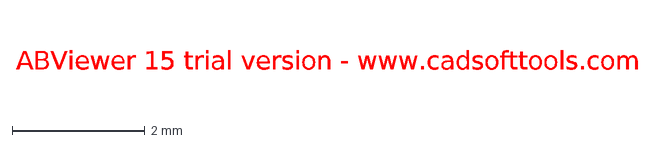
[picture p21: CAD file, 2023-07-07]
Références Composants/LILYGO T-SIM7000G - ESP32/Lilygo GitHub - Modèle 3D/T-SIM7000G(6.08)_DODO.dxf
T-SIM7000G(6.08).stp
Instance
NOT SPECIFIED
ABViewer 15 trial version - www.cadsofttools.com

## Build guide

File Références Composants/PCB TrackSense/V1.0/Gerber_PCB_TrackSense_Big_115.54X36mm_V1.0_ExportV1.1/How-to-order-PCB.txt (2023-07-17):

How to Order PCB

Please refer to:
https://docs.easyeda.com/en/PCB/Order-PCB

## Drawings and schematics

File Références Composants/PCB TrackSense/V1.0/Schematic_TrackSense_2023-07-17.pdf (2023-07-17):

# Speaker pi zo lectrique | Boutons

# Connecteurs I2C

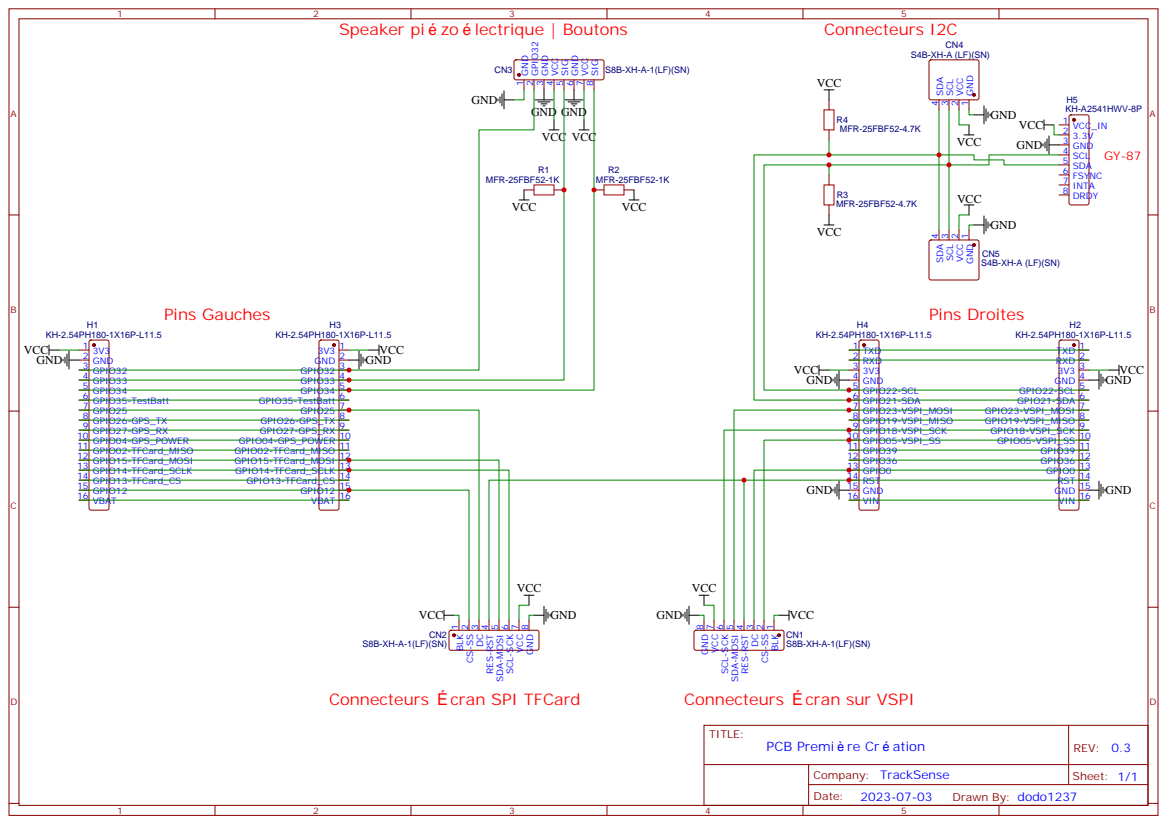
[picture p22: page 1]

Connecteurs cran SPI TFCard

Connecteurs cran sur VSPI

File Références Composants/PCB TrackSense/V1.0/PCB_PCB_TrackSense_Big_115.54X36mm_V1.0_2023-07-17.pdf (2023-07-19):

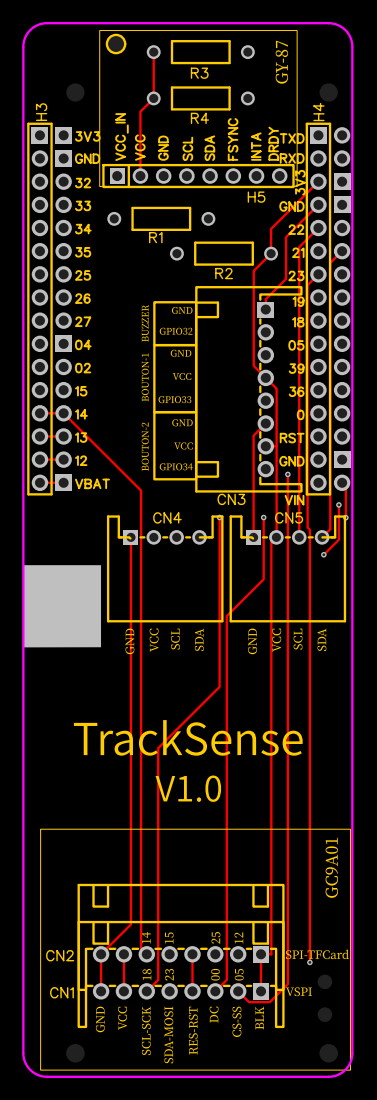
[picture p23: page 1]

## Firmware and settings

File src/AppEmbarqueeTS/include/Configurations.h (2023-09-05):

#pragma once
#include <Arduino.h>


/*----- DEBUG -----*/
#define DEBUG_BUTTONS false


/*----- Screen -----*/
#define SPI_TFCard 0 // 1 = SPI, 0 = VSPI

#if SPI_TFCard

    #define TFT_BL_BLK -1       // LED back-light
    #define TFT_CS_SS 12        // 25       // Chip select control pin
    #define TFT_DC 25           // 02          // Data Command control pin
    #define TFT_RES_RST -1      // Reset pin (could connect to Arduino RESET pin)
    #define TFT_SDA_DIN_MOSI 15 // In some display driver board, it might be written as "SDA" and so on.
    #define TFT_SCL_CLK_SCK 14  // In some display driver board, it might be written as "SCL" and so on.
    // #define TFT_MISO 02          // Ne semble pas être utile, car non tactile

#else // VSPI

    #define TFT_BL_BLK -1       // LED back-light
    #define TFT_CS_SS 05        // 25     // Chip select control pin
    #define TFT_DC 00           // 19        // Data Command control pin
    #define TFT_RES_RST -1      // Reset pin (could connect to Arduino RESET pin)
    #define TFT_SDA_DIN_MOSI 23 // In some display driver board, it might be written as "SDA" and so on.
    #define TFT_SCL_CLK_SCK 18  // In some display driver board, it might be written as "SCL" and so on.
    // #define TFT_MISO 19          // Ne semble pas être utile, car non tactile

#endif

/*----- SD Card -----*/
#define PIN_SDCARD_MOSI 15
#define PIN_SDCARD_SCLK 14
#define PIN_SDCARD_CS 13
#define PIN_SDCARD_MISO 2
#define PIN_SDCARD_LED 12

#define SDCARD_ROOT_PATH "/rd"
#define SDCARD_FILE_EXTENSION ".csv"

/*----- LilyGO T-SIM7000G (GPS, LTE) -----*/
#define GPS_UART_BAUD   115200
#define PIN_GPS_LTE_DTR 25
#define PIN_GPS_LTE_TX 27 // 26
#define PIN_GPS_LTE_RX 26 // 27
#define PIN_GPS_LTE_PWR 4
#define TINY_GSM_MODEM_SIM7000  // Utile ???
#define TINY_GSM_RX_BUFFER 1024 // Set RX buffer to 1Kb
#define MINIMUM_DISTANCE_TO_ADD_POSITION 10

/*----- Accelerometer, Gyroscope, Compass, Temperature -----*/
#define PIN_GY87_SDA 21
#define PIN_GY87_SCL 22


/*----- Buzzer -----*/
#define PIN_BUZZER 32


/*----- Buttons -----*/
#define PIN_BUTTON1 33
#define PIN_BUTTON2 34
#define BUTTON_LONG_PRESS_DURATION_MS 2000
#define BUTTON_INACTIVITY_TIME_MS 10000


/*----- BLE -----*/
#define BLE_DEVICE_NAME "TrackSense"
#define BLE_PIN_CODE "123456"
#define BLE_TRUE "true"
#define BLE_FALSE "false"

// Service et caracterisiques pour CompletedRide
#define BLE_COMPLETED_RIDE_SERVICE_UUID "62ffab64-3646-4fb9-88d8-541deb961192"
#define BLE_COMPLETED_RIDE_CHARACTERISTIC_ID "51656aa8-b795-427f-a96c-c4b6c57430dd"
#define BLE_COMPLETED_RIDE_CHARACTERISTIC_ROUTE_ID "17072e79-57c3-4aa2-a71e-02dea60b5804"
#define BLE_COMPLETED_RIDE_CHARACTERISTIC_MAX_SPEED "f3c6a5a1-c56a-4300-9e33-1e6f5505d3de"
#define BLE_COMPLETED_RIDE_CHARACTERISTIC_AVG_SPEED "e4c18d44-dde8-4344-982a-404260c08056"
#define BLE_COMPLETED_RIDE_CHARACTERISTIC_DATE_BEGIN "e3c59927-31f2-4821-b598-6ac659cc4515"
#define BLE_COMPLETED_RIDE_CHARACTERISTIC_DATE_END "c3102e0c-3e02-4d3b-a35f-147d02c08c42"
#define BLE_COMPLETED_RIDE_CHARACTERISTIC_DURATION "e3de9b11-f709-4d56-8717-b1faf0f0b3ef"
#define BLE_COMPLETED_RIDE_CHARACTERISTIC_DISTANCE "0f2c291c-76b5-4511-a103-530a83b626c4"
#define BLE_COMPLETED_RIDE_CHARACTERISTIC_POINTS "42154deb-5828-4876-8d4f-eaec38fa1ea7"
#define BLE_COMPLETED_RIDE_CHARACTERISTIC_NUMBER_OF_POINTS "86abb0bc-770e-4887-a6ff-47615669fcd6"
#define BLE_COMPLETED_RIDE_CHARACTERISTIC_NUMBER_OF_FALLS "3d29747b-7a8a-4df0-a8e9-21dc2cc90d89"
#define BLE_COMPLETED_RIDE_CHARACTERISTIC_IS_READY "9456444a-4b5f-11ee-be56-0242ac120002"
#define BLE_COMPLETED_RIDE_CHARACTERISTIC_IS_RECEIVED "08382f5e-4b60-11ee-be56-0242ac120002"

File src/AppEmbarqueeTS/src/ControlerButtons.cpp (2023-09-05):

#include "ControlerButtons.h"

ControlerButtons::ControlerButtons(TrackSenseProperties *trackSenseProperties) : _trackSenseProperties(trackSenseProperties),
                                                                                 _button1(nullptr),
                                                                                 _button2(nullptr),
                                                                                 // _isPressedButton1(false),
                                                                                 // _isPressedButton2(false),
                                                                                 _finalStateButton1(0),
                                                                                 _finalStateButton2(0)
{
    this->_button1 = new ButtonTactile(PIN_BUTTON1);
    this->_button2 = new ButtonTactile(PIN_BUTTON2);
}

ControlerButtons::~ControlerButtons()
{
}

void ControlerButtons::tick()
{
    // this->_isPressedButton1 = this->_button1->getIsPressedButton();   // 0 == not pressed    // 1 == pressed
    // this->_isPressedButton2 = this->_button2->getIsPressedButton();

    this->_finalStateButton1 = this->_button1->getFinalState(); // 0 == not pressed    // 1 == short press    // 2 == long press    // 3 == double short press
    this->_finalStateButton2 = this->_button2->getFinalState();

    this->_trackSenseProperties->PropertiesButtons._TEST_Button1State = this->_finalStateButton1;
    this->_trackSenseProperties->PropertiesButtons._TEST_Button2State = this->_finalStateButton2;

    if (this->_finalStateButton1 == 0 & this->_finalStateButton2 == 0) // not pressed
    {
        Serial.println("No button pressed");
    }
    else if (this->_finalStateButton1 == 1 & this->_finalStateButton2 == 0) // short press button 1
    {
        /* Change Screen Menu Up */
        Serial.println("Button 1 SHORT press");
        this->changePageUp();
    }
    else if (this->_finalStateButton1 == 0 & this->_finalStateButton2 == 1) // short press button 2
    {
        /* Change Screen Menu Down */
        Serial.println("Button 2 SHORT press");
        this->changePageDown();
    }
    else if (this->_finalStateButton1 == 2 & this->_finalStateButton2 == 0) // long press button 1
    {
        /* Start/Stop Ride */
        Serial.println("Button 1 LONG press");

        if (this->_trackSenseProperties->PropertiesTS._isRideFinished == false)
        {
            if (this->_trackSenseProperties->PropertiesTS._isRideStarted)
            {
                this->finishRide();
            }
            else
            {
                this->startRide();
            }
        }
    }
    else if (this->_finalStateButton1 == 0 & this->_finalStateButton2 == 2) // long press button 2
    {
        /* Pause/Restart Ride */
        Serial.println("Button 2 LONG press");

        if (this->_trackSenseProperties->PropertiesTS._isRideStarted)
        {
            if (this->_trackSenseProperties->PropertiesTS._isRidePaused)
            {
                this->restartRide();
            }
            else
            {
                this->pauseRide();
            }
        }
    }
    else if (this->_finalStateButton1 == 3 & this->_finalStateButton2 == 0) // double short press button 1
    {
        /* Trigger The Buzzer */
        Serial.println("Button 1 DOUBLE SHORT press");
        this->makeNoiseBuzzer();
    }
    else if (this->_finalStateButton1 == 0 & this->_finalStateButton2 == 3) // double short press button 2
    {
        /* Trigger The Buzzer */
        Serial.println("Button 2 DOUBLE SHORT press");
        this->makeNoiseBuzzer();
    }
    else if (this->_finalStateButton1 == 1 & this->_finalStateButton2 == 1) // short press button 1 and 2
    {
        /* Activate GoHome Mode */
        Serial.println("Buttons 1 and 2 SHORT press");
        this->goHome();
    }
    else if (this->_finalStateButton1 == 2 & this->_finalStateButton2 == 2) // long press button 1 and 2
    {
        /* Trigger The Buzzer */
        Serial.println("Buttons 1 and 2 LONG press");
        this->makeNoiseBuzzer();
    }
    else
    {
        /* Nothing Good Happened... */
        Serial.println("BUTTONS ERROR !!!");
    }
}

void ControlerButtons::changePageUp()
{
    // this->_trackSenseProperties->PropertiesScreen.nextPage();
    this->_trackSenseProperties->PropertiesScreen.setActivePage(1);
}

void ControlerButtons::changePageDown()
{
}

void ControlerButtons::startRide()
{
    this->_trackSenseProperties->PropertiesTS._isRideStarted = true;
    this->_trackSenseProperties->PropertiesTS._isRideFinished = false;
}

void ControlerButtons::finishRide()
{
    this->_trackSenseProperties->PropertiesTS._isRideFinished = true;
    // this->_trackSenseProperties->PropertiesTS._isRideStarted = false;
}

void ControlerButtons::pauseRide()
{
    this->_trackSenseProperties->PropertiesTS._isRidePaused = true;
}

void ControlerButtons::restartRide()
{
    this->_trackSenseProperties->PropertiesTS._isRidePaused = false;
}

void ControlerButtons::makeNoiseBuzzer()
{
    this->_trackSenseProperties->PropertiesBuzzer._isBuzzerOn = true;
}

void ControlerButtons::goHome()
{
    this->_trackSenseProperties->PropertiesScreen._isHomePage = true;
}

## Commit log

2023-07-07 Test d'ajout d'un code Pin pour la connexion
2023-07-07 Ajout Références Composants
    [0508.stp, EXUUNN EX636-7.26 3-Port v3.iges, Liste des composants.xlsx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]
2023-07-08 Ajout de quelques références
2023-07-08 Ajout de références
2023-07-14 Correction des pins
2023-07-14 Ajout Gerber File
    [Drill_NPTH_Through.DRL, Drill_PTH_Through.DRL, Drill_PTH_Through_Via.DRL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]
2023-07-17 Update fichiers Gerber PCB V1.0 Final
    [BOM_TrackSense_2023-07-17.csv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]
2023-07-19 Updates fichiers du Wiki et Modifier les dossiers de modèles 3D
    [0508.stp, PCB_TrackSense_Big_115.54X36mm_V1.0_2023-07-17.dxf]
2023-07-20 Ajout des fichiers de production du PCB de JLCPCB
2023-08-18 Test avec bouton, buzzer et écran
    [main.cpp]
2023-08-22 fichiers .stp
    [0508.stp]
2023-08-24 Création diagramme de classe
2023-08-29 Test dessin de niveau de batterie
2023-08-31 Ajout des fichiers tests
2023-09-01 Ajouter un dossier Tests pour mieux classer les fichiers
2023-09-01 Changer arborescence des dossiers et créer Projet TS
2023-09-01 Initialisation du projet de base avec blibliothèques et classes
    [Comparaison t-sim7000G & t-sim7600g-h.step]
2023-09-01 Création des classes de bases
2023-09-01 Ajout fichiers configurations
    [Configurations.h]
2023-09-02 Ajout méthode dans les Interfaces
2023-09-02 Corriger les numéros de pin
    [Configurations.h]
2023-09-02 Ajout des méthodes Tick()
2023-09-02 Ajout méthode Tick() de l'écran avec un exemple
2023-09-02 Ajout méthode Tick() de la carteSD avec un exemple
2023-09-02 Ajout du système de bouton avec un exemple
2023-09-02 Rendre public les données membres de TrackSenseProperties
2023-09-02 Créer la méthode principale Execute() du Program
2023-09-02 modifier diagramme de classe
2023-09-02 Ajouter pin I2C pour GY-87
    [Configurations.h]
2023-09-04 Changer le fonctionnement des boutons. Ajout pression longue
2023-09-04 Changer config boutons pression longue
    [Configurations.h]
2023-09-04 Classer les propriétées TS avec des Structs !
2023-09-04 Modifier code selon les nouveaux structs de TSProperties
2023-09-04 Rendre l'héritage des Modules public
2023-09-04 Préparer test des boutons
2023-09-04 1ère tentative pas parfaite gestions des boutons
    [Configurations.h]
2023-09-04 Ajout propriétées UUID pour CompletedRide dans BLE
    [Configurations.h]
2023-09-04 Ajout des méthodes, class et membres pour l'envoie d'un completedRide
    [Configurations.h]
2023-09-04 Suppression du const dans les méthodes tick
2023-09-05 Création GPS
    [Configurations.h]
2023-09-05 Activer l'antenne GPS avec la pin 4
    [Configurations.h]
2023-09-05 Ajout méthode pour SET la page avec un id et GET active page
2023-09-05 Debut SDCard
    [Configurations.h]
2023-09-05 Correction conflits
    [Configurations.h]
2023-09-05 Ajout PDF de référence des bibliothèques
